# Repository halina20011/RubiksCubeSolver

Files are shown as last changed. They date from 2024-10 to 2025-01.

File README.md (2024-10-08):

# RubiksCubeSolver
silly Rubik's Cube solver that will stand next to my desk and obsessively solve and scramble the cube, helping me procrastinate more by staring at it...

### PCB
2 layer board made with KiCad

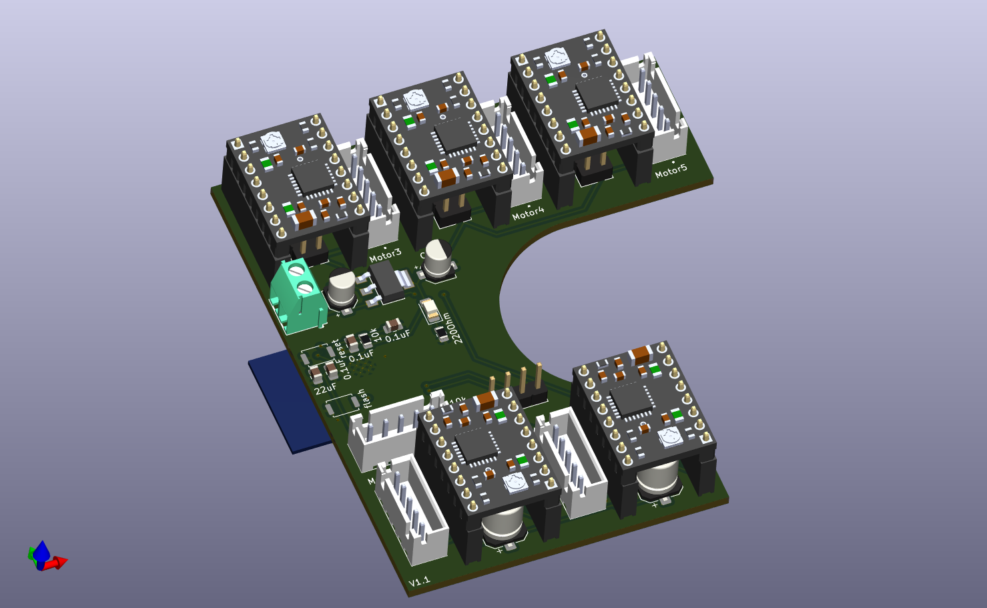
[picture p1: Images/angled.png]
angled


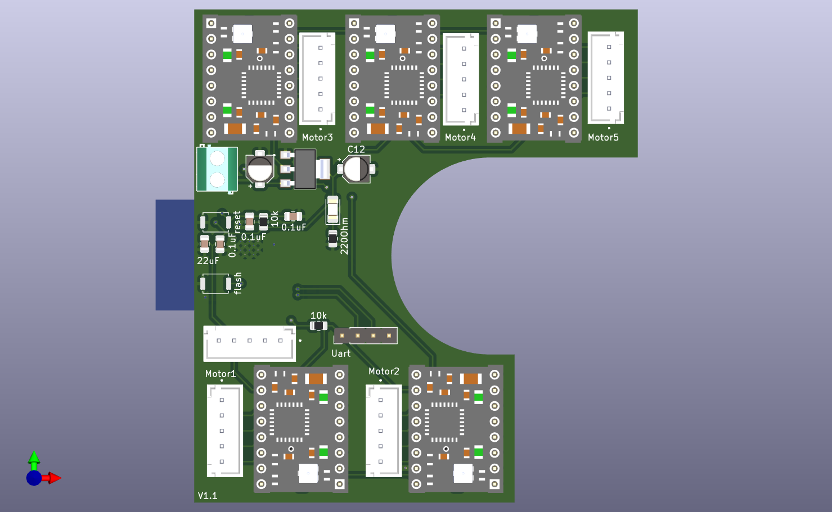
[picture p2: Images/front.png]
front


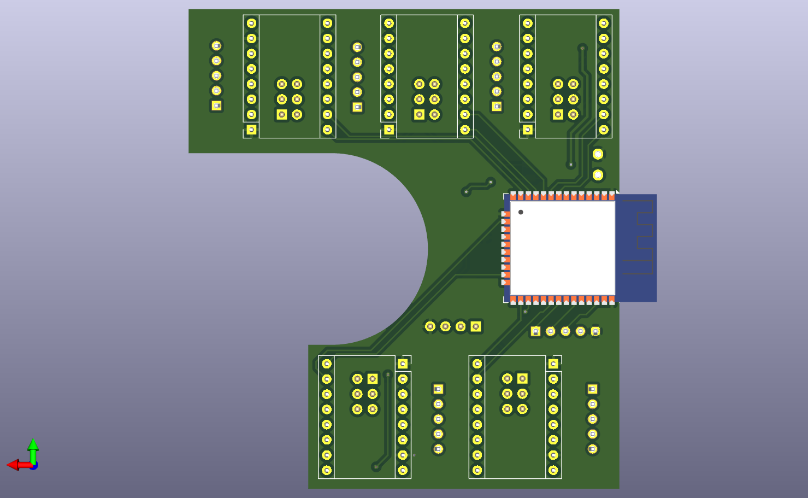
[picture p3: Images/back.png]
back


### cube solving algorithms
> TODO

### BOM
> TODO

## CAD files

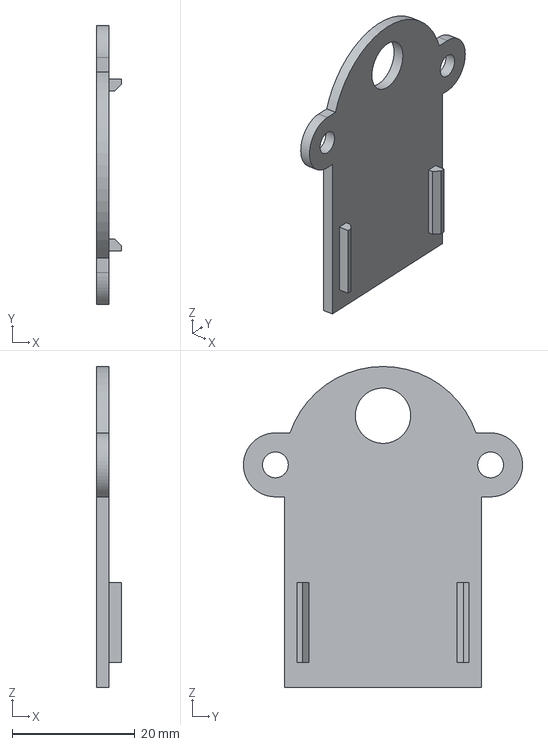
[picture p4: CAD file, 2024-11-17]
Model/Export/armEnclosurearm.step
4.00 x 45.4 x 52.2 mm

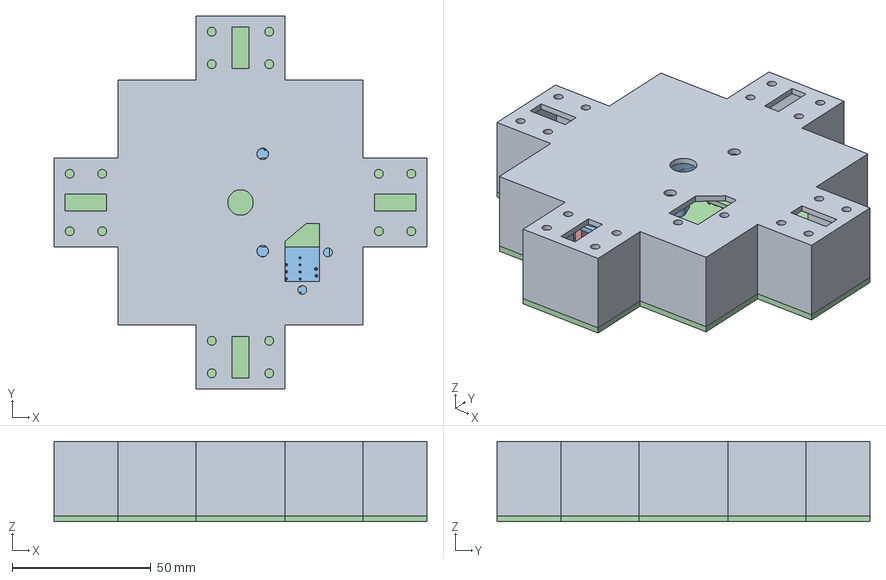
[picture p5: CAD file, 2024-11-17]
Model/rubiksCubeSolver.FCStd
134.4 x 134.4 x 29.0 mm
base
boardHolder
boardMotorHolder
B5B-XH-A(LF)(SN)
B5B-XH-A(LF)(SN)001
B5B-XH-A(LF)(SN)002
B5B-XH-A(LF)(SN)003
B5B-XH-A(LF)(SN)004
B5B-XH-A(LF)(SN)005
B5B-XH-A(LF)(SN)007
B5B-XH-A(LF)(SN)008
B5B-XH-A(LF)(SN)009
B5B-XH-A(LF)(SN)010
B5B-XH-A(LF)(SN)011
B5B-XH-A(LF)(SN)012
R_0805_2012Metric
B5B-XH-A(LF)(SN)014
B5B-XH-A(LF)(SN)015
B5B-XH-A(LF)(SN)016
B5B-XH-A(LF)(SN)017
B5B-XH-A(LF)(SN)018
B5B-XH-A(LF)(SN)019
C_0805_2012Metric
B5B-XH-A(LF)(SN)021
B5B-XH-A(LF)(SN)022
B5B-XH-A(LF)(SN)023
B5B-XH-A(LF)(SN)024
B5B-XH-A(LF)(SN)025
B5B-XH-A(LF)(SN)026
PinHeader_2x03_P254mm_Vertical
PinHeader_2x03_P254mm_Vertical001
CP_Elec_63x77
CP_Elec_63x078
TS1117BCW RPG
TS1117BCW RPG001
TS1117BCW RPG002
TS1117BCW RPG003
TS1117BCW RPG004
C_0805_2012Metric002
CP_Elec_63x079
CONN-TH_DB301V-3.5-2P-GN
CONN-TH_DB301V-3.5-2P-GN001
CONN-TH_DB301V-3.5-2P-GN002
CONN-TH_DB301V-3.5-2P-GN003
CONN-TH_DB301V-3.5-2P-GN004
CONN-TH_DB301V-3.5-2P-GN005
CONN-TH_DB301V-3.5-2P-GN006
CONN-TH_DB301V-3.5-2P-GN007
CONN-TH_DB301V-3.5-2P-GN008
CONN-TH_DB301V-3.5-2P-GN009
CONN-TH_DB301V-3.5-2P-GN010
CONN-TH_DB301V-3.5-2P-GN011
CONN-TH_DB301V-3.5-2P-GN012
CONN-TH_DB301V-3.5-2P-GN013
PinHeader_2x03_P254mm_Vertical002
LED_1206_3216Metric
CP_Elec_4x54
B5B-XH-A(LF)(SN)028
B5B-XH-A(LF)(SN)029
B5B-XH-A(LF)(SN)030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

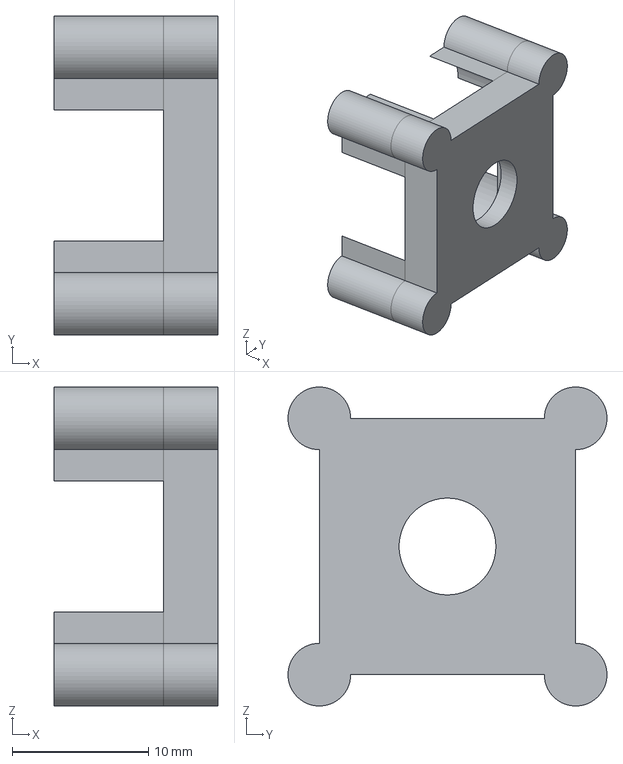
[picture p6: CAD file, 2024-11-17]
Model/Export/cubeConnector.step
12.0 x 23.4 x 23.4 mm

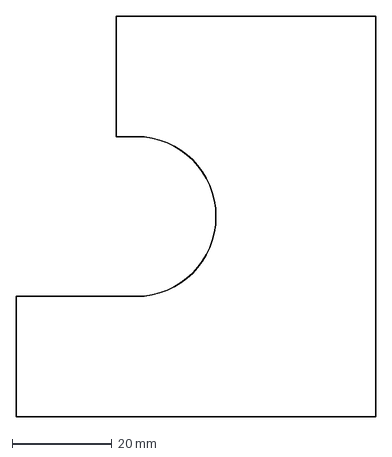
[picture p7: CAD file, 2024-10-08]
Model/pcbOutline.dxf
72.0 x 80.1 mm

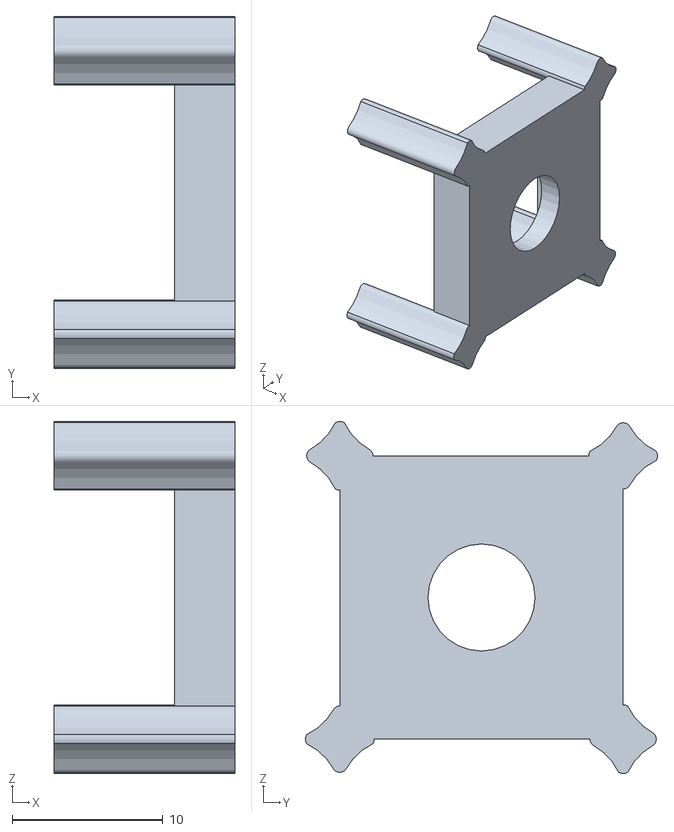
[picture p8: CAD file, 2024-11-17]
Model/Stl/rubiksCubeSolver-CubeConnector.stl
12.0 x 23.4 x 23.4

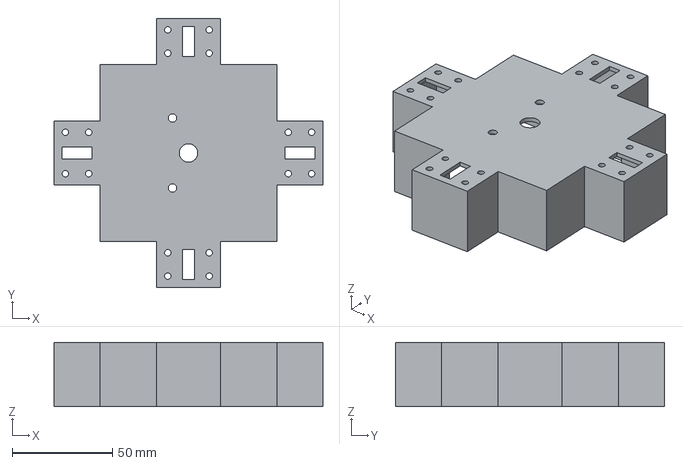
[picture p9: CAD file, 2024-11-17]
Model/Export/base.step
134.4 x 134.4 x 32.0 mm

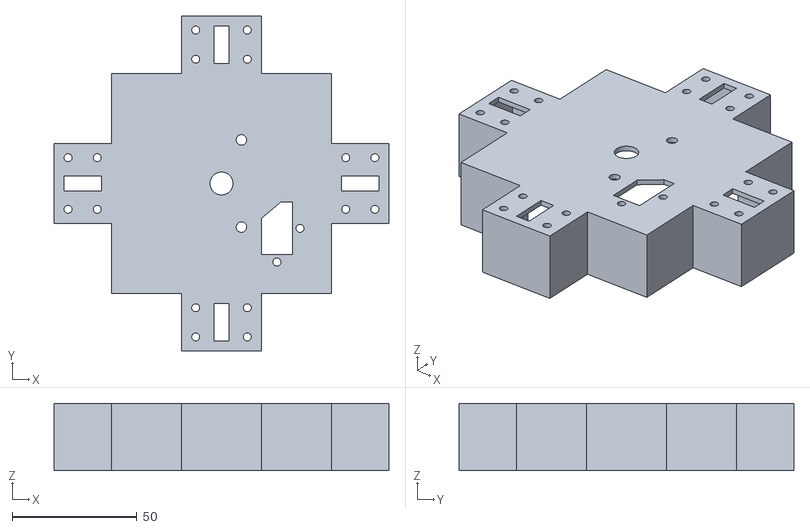
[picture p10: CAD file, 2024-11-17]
Model/Stl/rubiksCubeSolver-Basebase.stl
134.4 x 134.4 x 27.0

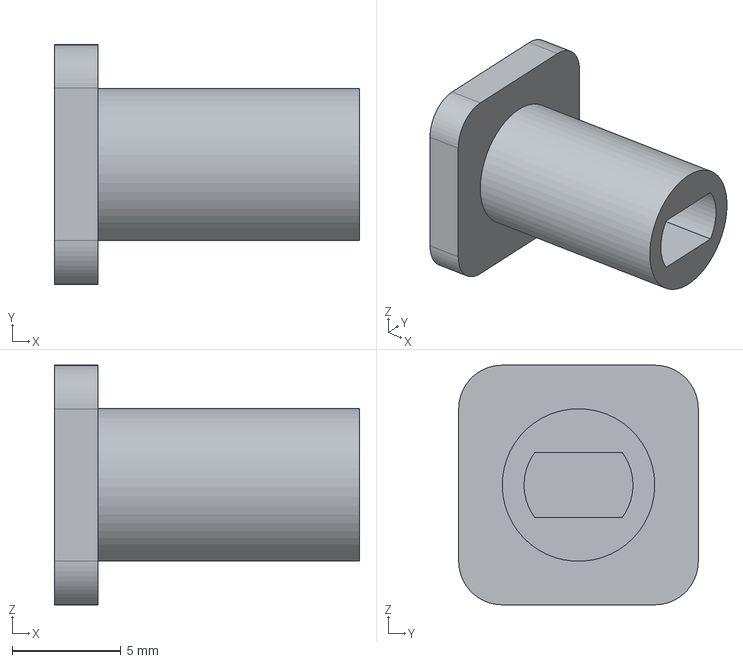
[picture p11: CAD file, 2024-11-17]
Model/Export/motorConnector.step
14.0 x 11.0 x 11.0 mm

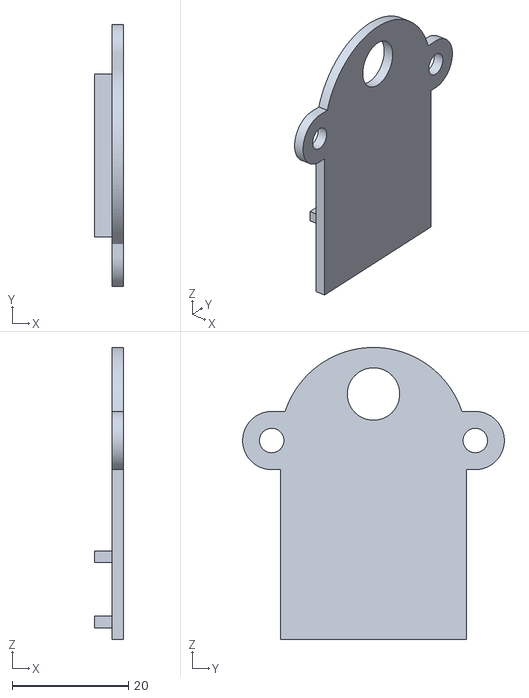
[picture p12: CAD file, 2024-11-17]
Model/Stl/rubiksCubeSolver-ArmPartArmEnclosure.stl
5.00 x 45.0 x 50.2

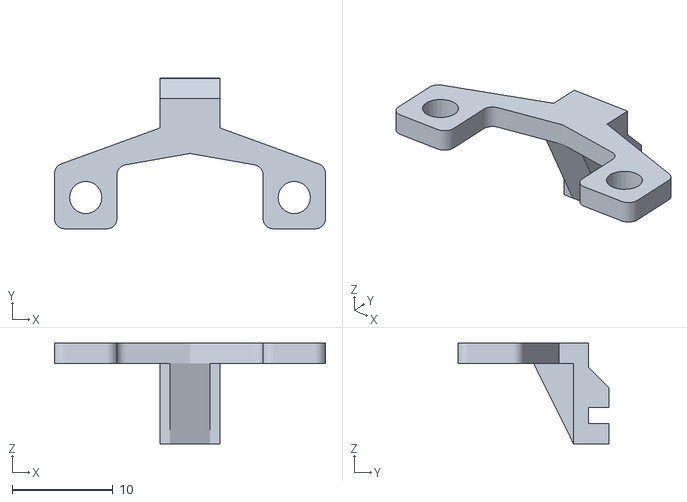
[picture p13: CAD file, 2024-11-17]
Model/Stl/rubiksCubeSolver-BaseboardHolder.stl
26.9 x 15.0 x 10.0

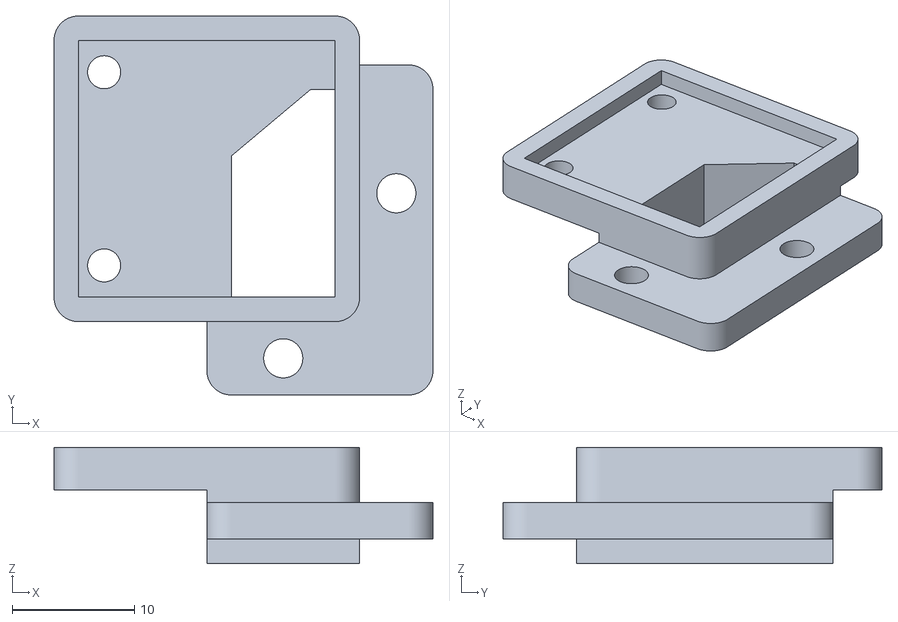
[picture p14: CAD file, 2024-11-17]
Model/Stl/sensorHolder.stl
31.0 x 31.0 x 9.50

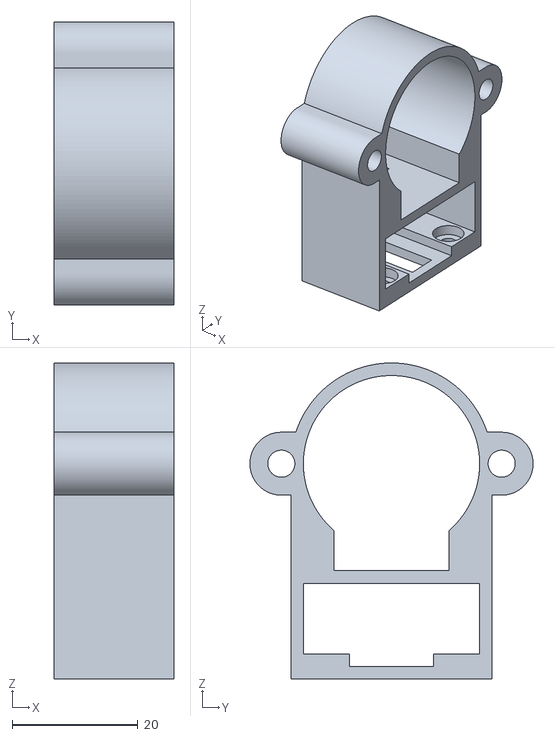
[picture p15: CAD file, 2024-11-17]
Model/Stl/rubiksCubeSolver-ArmPartArm.stl
19.0 x 45.0 x 50.2

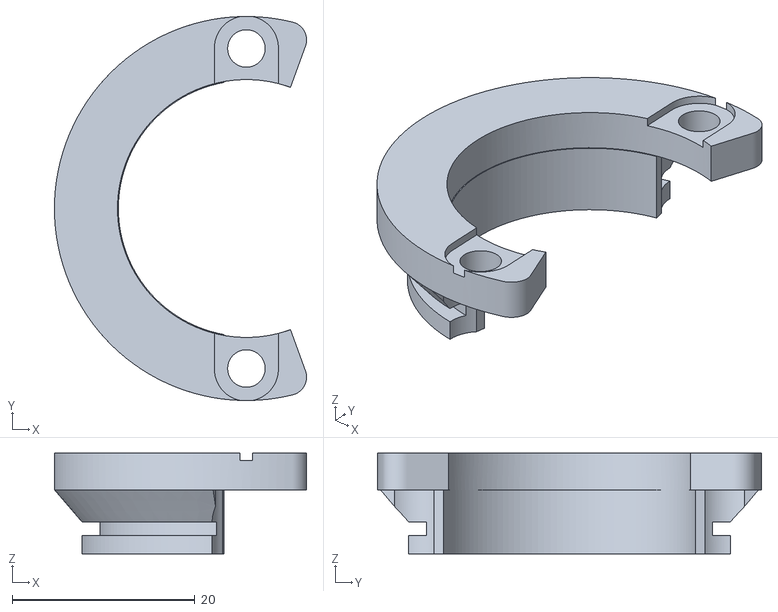
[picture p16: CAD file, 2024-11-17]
Model/Stl/rubiksCubeSolver-BaseboardMotorHolder.stl
27.6 x 42.0 x 11.0

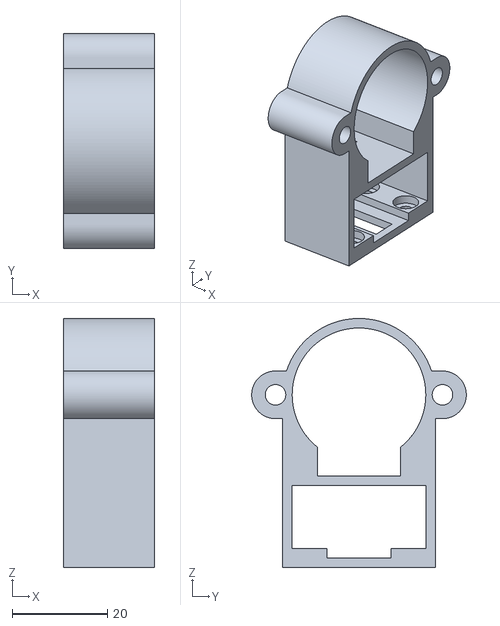
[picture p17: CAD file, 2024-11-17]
Model/Stl/arm.stl
19.0 x 45.0 x 52.2

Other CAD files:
Model/Stl/armEnclosure.3mf
Model/Stl/rubiksCubeSolver-MotorConnector.stl
Model/Stl/rubiksCubeSolver-ArmPartArmEnclosureHole.stl
Model/Stl/armEnclosure.stl
Model/Stl/base.stl
Model/Stl/cubeConnector.stl
Model/Stl/motorConnector.stl
Model/rubiksCube.blend

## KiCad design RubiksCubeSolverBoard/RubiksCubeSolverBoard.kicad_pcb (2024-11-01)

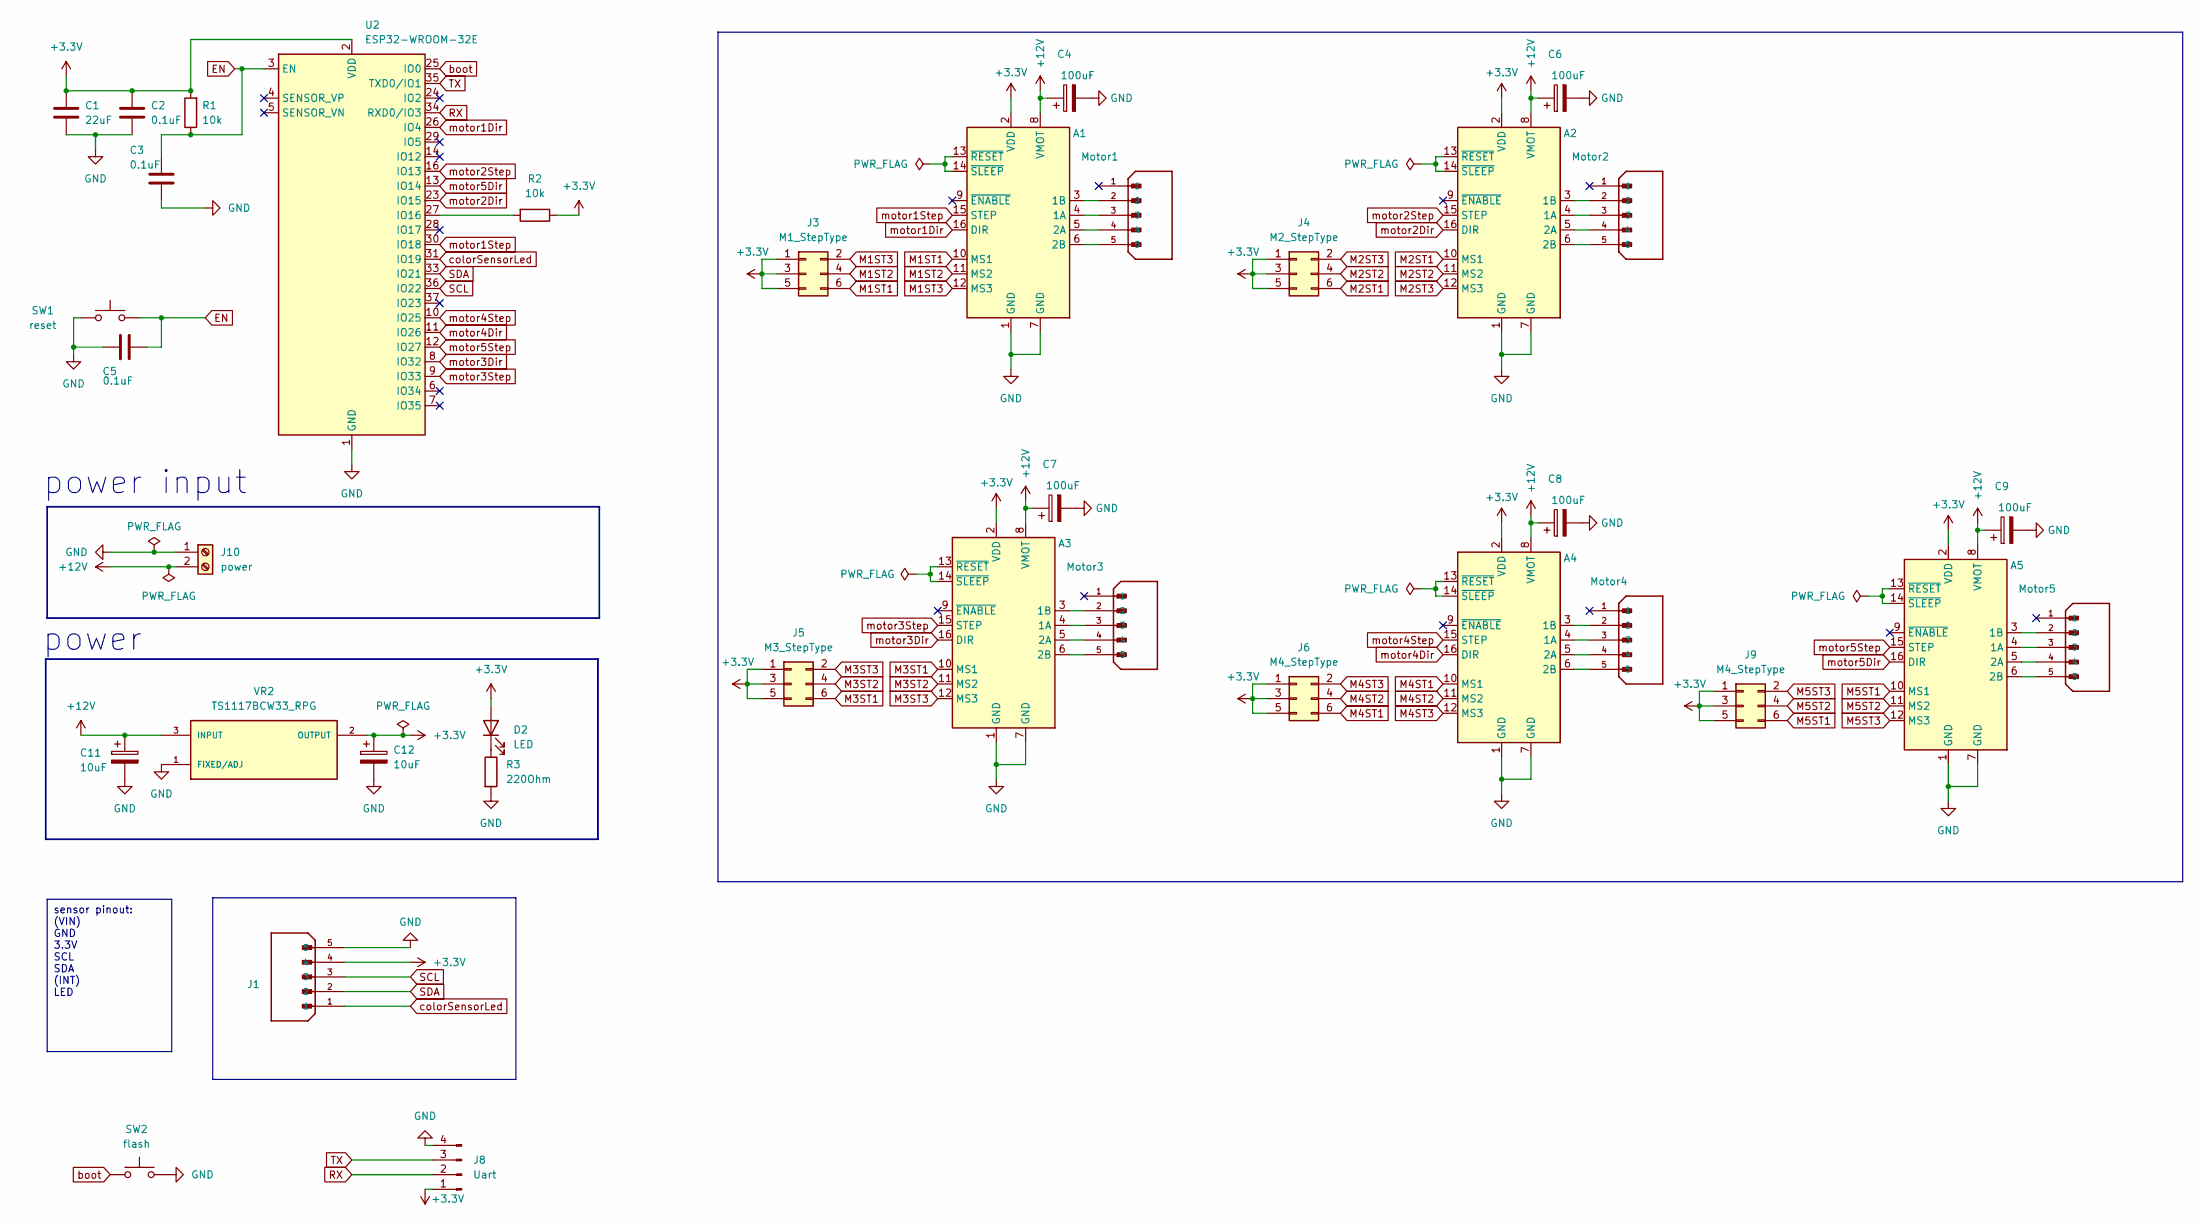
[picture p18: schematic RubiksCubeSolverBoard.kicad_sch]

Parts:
A1, A2, A3, A4, A5: Pololu_Breakout_A4988; A4988Mirrored
C1: 22uF; C_0805_2012Metric
C2, C3, C5: 0.1uF; C_0805_2012Metric
C4, C6, C7, C8, C9: 100uF; CP_Elec_6.3x7.7
C11, C12: 10uF; CP_Elec_4x5.4
D2: LED; LED_1206_3216Metric_Pad1.42x1.75mm_HandSolder
J1: colorSensor; JST_B5B-XH-A_LF__SN_; PARTREV N/A
J3: M1_StepType; PinHeader_2x03_P2.54mm_Vertical
J4: M2_StepType; PinHeader_2x03_P2.54mm_Vertical
J5: M3_StepType; PinHeader_2x03_P2.54mm_Vertical
J6, J9: M4_StepType; PinHeader_2x03_P2.54mm_Vertical
J7: Motor1; JST_B5B-XH-A_LF__SN_; PARTREV N/A
J8: Uart; PinHeader_1x04_P2.54mm_Vertical
J10: power; CONN-TH_DB301V-3.5-2P-GN
J14: Motor2; JST_B5B-XH-A_LF__SN_; PARTREV N/A
J18: Motor3; JST_B5B-XH-A_LF__SN_; PARTREV N/A
J22: Motor4; JST_B5B-XH-A_LF__SN_; PARTREV N/A
J26: Motor5; JST_B5B-XH-A_LF__SN_; PARTREV N/A
R1, R2: 10k; R_0805_2012Metric
R3: 220Ohm; R_0805_2012Metric
SW1: reset; SW_Push_SPST_NO_Alps_SKRK
SW2: flash; SW_Push_SPST_NO_Alps_SKRK
U2: ESP32-WROOM-32E; ESP32-WROOM-32D
VR2: TS1117BCW33_RPG; VREG_TS1117BCW33_RPG; PARTREV H1607

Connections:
+3.3V: A1.2 (VDD), A2.2 (VDD), A3.2 (VDD), A4.2 (VDD), A5.2 (VDD), C1.1, C2.1, C12.1, D2.2 (A), J1.4, J3.1, J3.3, J3.5, J4.1, J4.3, J4.5, J5.1, J5.3, J5.5, J6.1, J6.3, J6.5, J8.1, J9.1, J9.3, J9.5, R1.2, R2.1, U2.2 (VDD), VR2.2 (OUTPUT)
+12V: A1.8 (VMOT), A2.8 (VMOT), A3.8 (VMOT), A4.8 (VMOT), A5.8 (VMOT), C4.1, C6.1, C7.1, C8.1, C9.1, C11.1, J10.2, VR2.3 (INPUT)
EN: C3.1, C5.2, R1.1, SW1.2, U2.3 (EN)
GND: A1.1 (GND), A1.7 (GND), A2.1 (GND), A2.7 (GND), A3.1 (GND), A3.7 (GND), A4.1 (GND), A4.7 (GND), A5.1 (GND), A5.7 (GND), C1.2, C2.2, C3.2, C4.2, C5.1, C6.2, C7.2, C8.2, C9.2, C11.2, C12.2, J1.5, J8.4, J10.1, R3.2, SW1.1, SW2.2, U2.1 (GND), U2.15 (GND), U2.38 (GND), U2.39 (GND), VR2.1 (FIXED/ADJ)
M1ST1: A1.10 (MS1), J3.6
M1ST2: A1.11 (MS2), J3.4
M1ST3: A1.12 (MS3), J3.2
M2ST1: A2.10 (MS1), J4.6
M2ST2: A2.11 (MS2), J4.4
M2ST3: A2.12 (MS3), J4.2
M3ST1: A3.10 (MS1), J5.6
M3ST2: A3.11 (MS2), J5.4
M3ST3: A3.12 (MS3), J5.2
M4ST1: A4.10 (MS1), J6.6
M4ST2: A4.11 (MS2), J6.4
M4ST3: A4.12 (MS3), J6.2
M5ST1: A5.10 (MS1), J9.6
M5ST2: A5.11 (MS2), J9.4
M5ST3: A5.12 (MS3), J9.2
unnamed: A1.4 (1A), J7.3
unnamed: A1.3 (1B), J7.2
unnamed: A1.5 (2A), J7.4
unnamed: A1.6 (2B), J7.5
unnamed: A1.13 (~RESET), A1.14 (~SLEEP)
unnamed: A2.4 (1A), J14.3
unnamed: A2.3 (1B), J14.2
unnamed: A2.5 (2A), J14.4
unnamed: A2.6 (2B), J14.5
unnamed: A2.13 (~RESET), A2.14 (~SLEEP)
unnamed: A3.4 (1A), J18.3
unnamed: A3.3 (1B), J18.2
unnamed: A3.5 (2A), J18.4
unnamed: A3.6 (2B), J18.5
unnamed: A3.13 (~RESET), A3.14 (~SLEEP)
unnamed: A4.4 (1A), J22.3
unnamed: A4.3 (1B), J22.2
unnamed: A4.5 (2A), J22.4
unnamed: A4.6 (2B), J22.5
unnamed: A4.13 (~RESET), A4.14 (~SLEEP)
unnamed: A5.4 (1A), J26.3
unnamed: A5.3 (1B), J26.2
unnamed: A5.5 (2A), J26.4
unnamed: A5.6 (2B), J26.5
unnamed: A5.13 (~RESET), A5.14 (~SLEEP)
unnamed: D2.1 (K), R3.1
unnamed: R2.2, U2.27 (IO16)
RX: J8.2, U2.34 (RXD0/IO3)
SCL: J1.3, U2.36 (IO22)
SDA: J1.2, U2.33 (IO21)
TX: J8.3, U2.35 (TXD0/IO1)
boot: SW2.1, U2.25 (IO0)
colorSensorLed: J1.1, U2.31 (IO19)
motor1Dir: A1.16 (DIR), U2.26 (IO4)
motor1Step: A1.15 (STEP), U2.30 (IO18)
motor2Dir: A2.16 (DIR), U2.23 (IO15)
motor2Step: A2.15 (STEP), U2.16 (IO13)
motor3Dir: A3.16 (DIR), U2.8 (IO32)
motor3Step: A3.15 (STEP), U2.9 (IO33)
motor4Dir: A4.16 (DIR), U2.11 (IO26)
motor4Step: A4.15 (STEP), U2.10 (IO25)
motor5Dir: A5.16 (DIR), U2.13 (IO14)
motor5Step: A5.15 (STEP), U2.12 (IO27)

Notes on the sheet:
sensor pinout: (VIN) GND 3.3V SCL SDA (INT) LED
power input
power

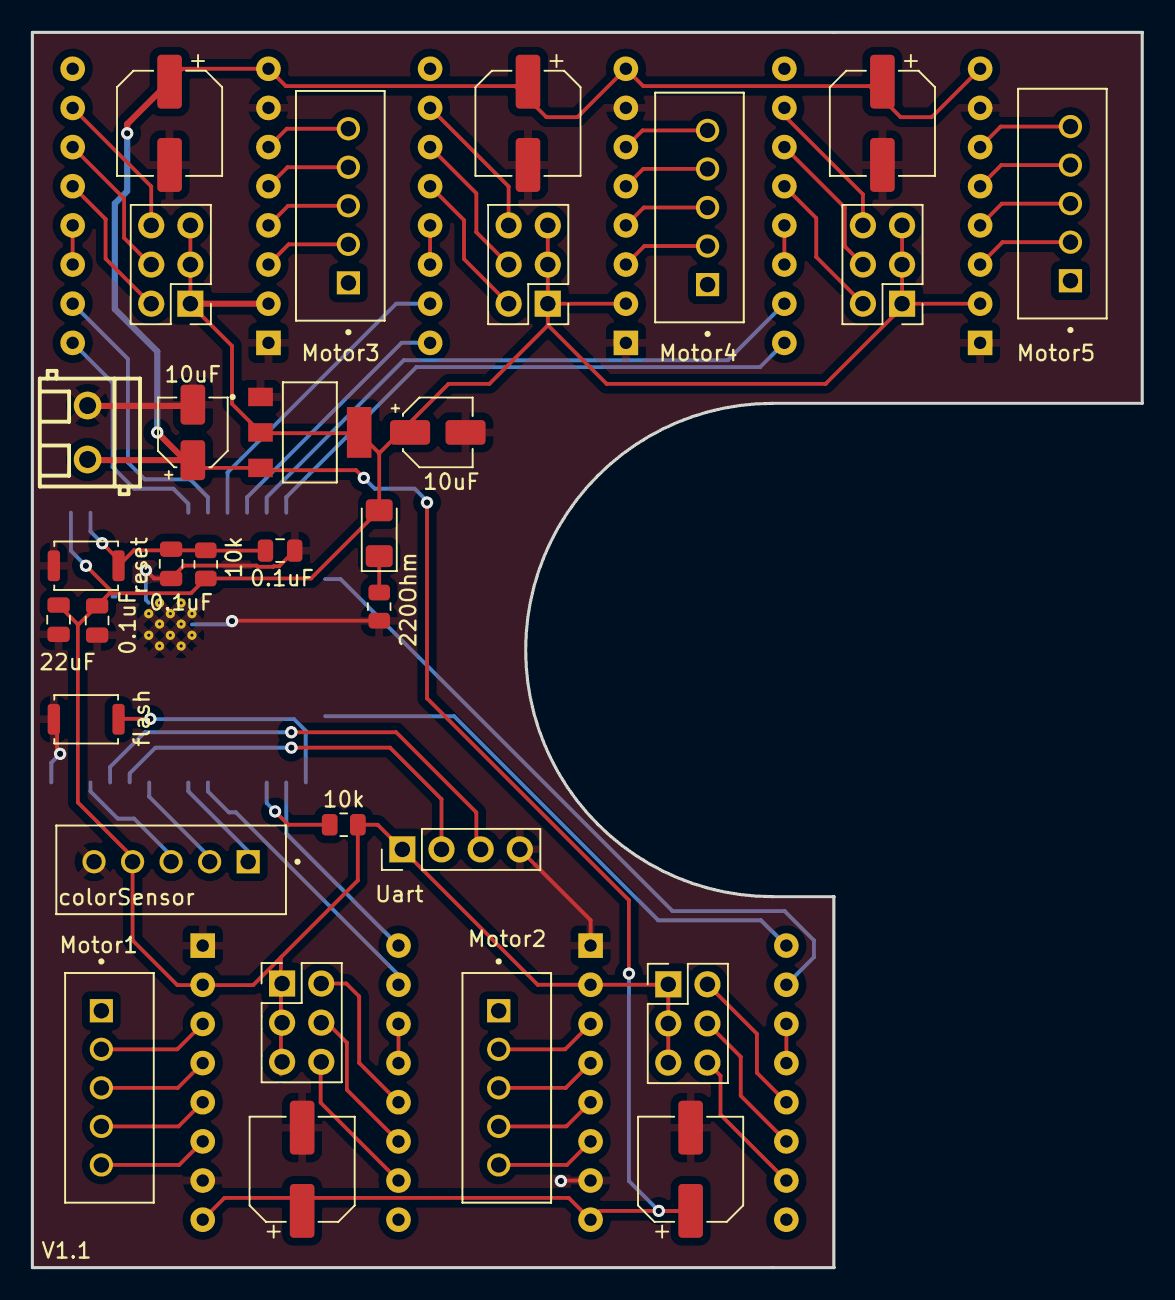
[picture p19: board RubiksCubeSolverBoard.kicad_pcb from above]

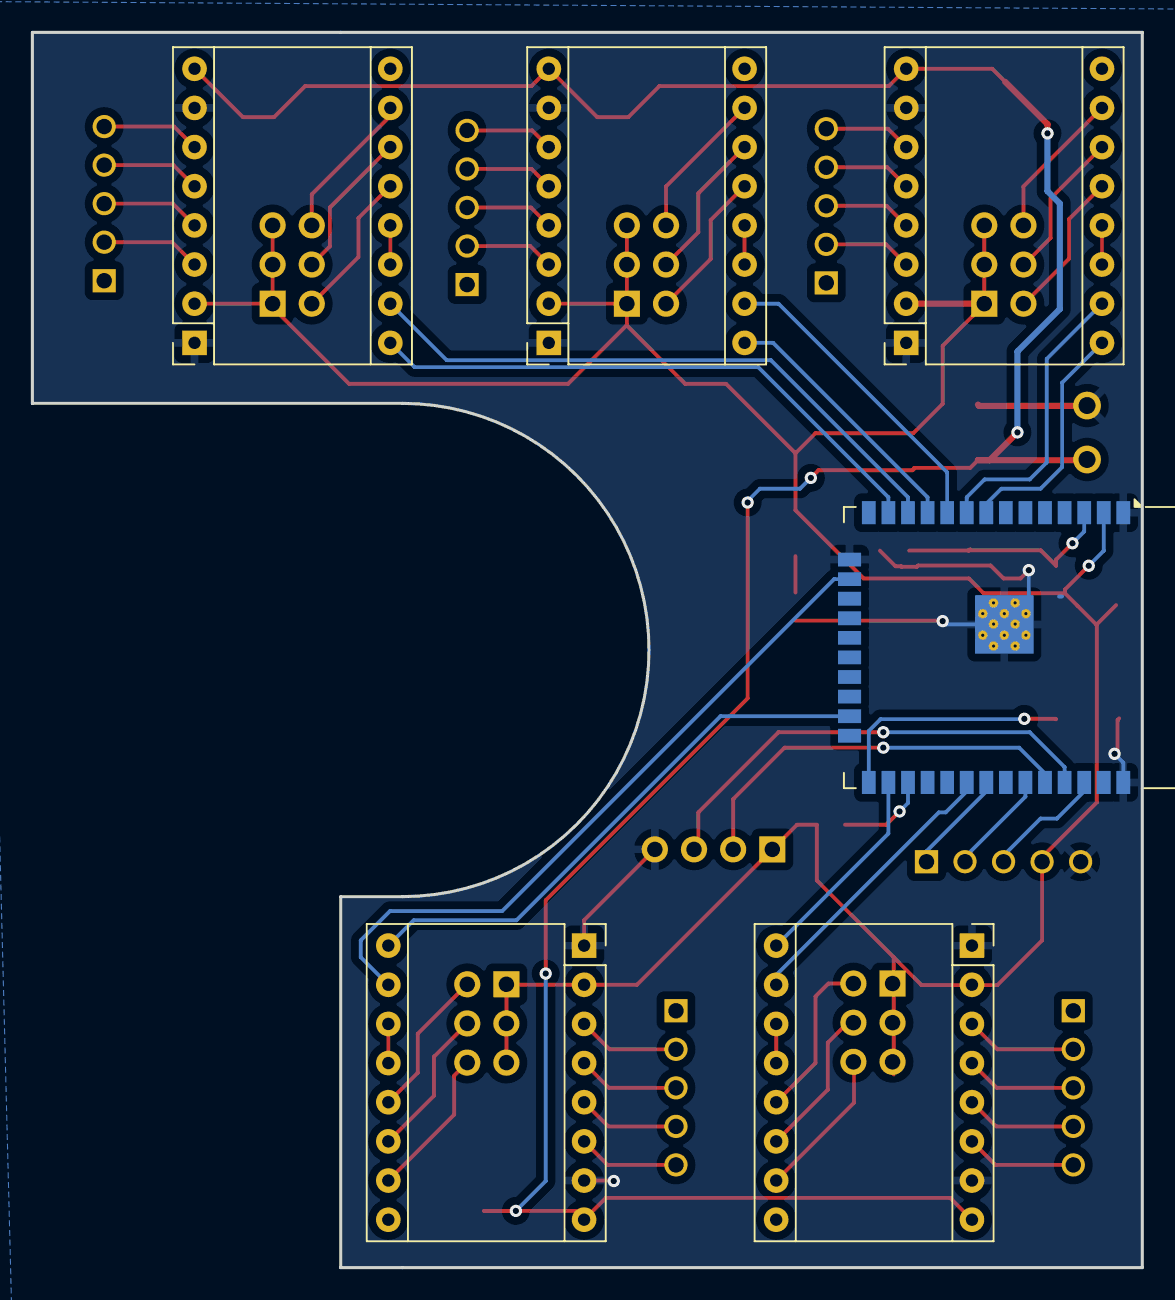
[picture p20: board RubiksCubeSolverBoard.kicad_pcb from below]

Board: 2 copper layers, 72.0 x 80.1 mm, 37 parts (6 on the bottom side), 62 nets.

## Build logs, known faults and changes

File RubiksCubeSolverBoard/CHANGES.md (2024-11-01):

### Version 1
- BUG: wrong motor connector connections

### Version 1.1
- FIX: wrong motor connector connection
- changed power connector to screw terminal
- show component values on silk screen
- replaced radial capacitors with smd ones
- stepper motor step mode connector changed to 02x03 header
- added pcb version number

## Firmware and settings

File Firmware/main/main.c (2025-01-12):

#include "motor.h"
#include "pinout.h"

#include "nvs_flash.h"

#include "sensor.h"
#include "wifi.h"
#include "mcode.h"

void mainLoop(){
    while(1){
        processCommandQueue();
    }
}

void app_main(void){
    ESP_ERROR_CHECK(nvs_flash_init());

    commandQueueInit();
    // sensorInit(1);
    motorsInit();
    wifiInit();
    xTaskCreate(mainLoop, "MainLoop", 4096, NULL, 2, NULL);
    
    // bool led = 0;
    // struct Color color = {};
    // while(1){
    //     // motorTest(&m1);
    //     // motorTest(&m4);
    //     // sensorLed(led);
    //     getColor(&color);
    //     printf("%i %i %i\n", color.r, color.g, color.b);
    //     // led = !led;
    //     vTaskDelay(pdMS_TO_TICKS(100));
    // }
}

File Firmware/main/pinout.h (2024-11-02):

#ifndef __PINOUT__
#define __PINOUT__

// #include "freertos/FreeRTOS.h"
// #include "driver/gpio.h"

#define MOTOR1_DIR  GPIO_NUM_4
#define MOTOR1_STEP GPIO_NUM_18

#define MOTOR2_DIR  GPIO_NUM_15
#define MOTOR2_STEP GPIO_NUM_13

#define MOTOR3_DIR  GPIO_NUM_32
#define MOTOR3_STEP GPIO_NUM_33

#define MOTOR4_DIR  GPIO_NUM_26
#define MOTOR4_STEP GPIO_NUM_25

#define MOTOR5_DIR  GPIO_NUM_14
#define MOTOR5_STEP GPIO_NUM_27

#endif

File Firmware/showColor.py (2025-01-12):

import tkinter as tk
import serial

# Configuration
SERIAL_PORT = "/dev/ttyUSB0"  # Path to the serial device
BAUD_RATE = 115200  # Match the baud rate of your device
WINDOW_WIDTH = 800
WINDOW_HEIGHT = 600

def read_rgb_values(serial_connection):
    """Reads a line from the serial port and parses it into RGB values."""
    try:
        line = serial_connection.readline().decode("utf-8").strip()
        r, g, b = map(int, line.split())
        return (r, g, b)
    except (ValueError, UnicodeDecodeError):
        print(f"Invalid line received: {line}")
        return None

def update_color(canvas, serial_connection):
    """Reads RGB values and updates the canvas color."""
    color = read_rgb_values(serial_connection)
    if color:
        # Convert RGB to hex color
        hex_color = f"#{color[0]:02x}{color[1]:02x}{color[2]:02x}"
        canvas.config(bg=hex_color)
    # Continue waiting for the next line
    canvas.after(1, update_color, canvas, serial_connection)

def main():
    # Open the serial connection
    try:
        serial_connection = serial.Serial(SERIAL_PORT, BAUD_RATE, timeout=None)  # Blocking mode
    except serial.SerialException as e:
        print(f"Error opening serial port: {e}")
        return

    # Set up the tkinter window
    root = tk.Tk()
    root.title("Color Display")
    root.geometry(f"{WINDOW_WIDTH}x{WINDOW_HEIGHT}")
    canvas = tk.Canvas(root, width=WINDOW_WIDTH, height=WINDOW_HEIGHT)
    canvas.pack(fill="both", expand=True)

    # Start the update loop
    update_color(canvas, serial_connection)
    root.mainloop()

    # Close the serial connection when done
    serial_connection.close()

if __name__ == "__main__":
    main()

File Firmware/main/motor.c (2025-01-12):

#include "motor.h"

struct Motor motors[5] = {};

void motorsInit(){
    motorInit(&motors[0], MOTOR1_DIR, MOTOR1_STEP);
    motorInit(&motors[1], MOTOR2_DIR, MOTOR2_STEP);
    motorInit(&motors[2], MOTOR3_DIR, MOTOR3_STEP);
    motorInit(&motors[3], MOTOR4_DIR, MOTOR4_STEP);
    motorInit(&motors[4], MOTOR5_DIR, MOTOR5_STEP);
}

void motorInit(struct Motor *motor, uint8_t dirPin, uint8_t stepPin){
    motor->dirPin = dirPin;
    motor->stepPin = stepPin;

    gpio_config_t pinConf = {};
    // dissable interrupt
    pinConf.intr_type = GPIO_INTR_DISABLE;
    // set them as output mode
    pinConf.mode = GPIO_MODE_OUTPUT;
    // bit masl for targeted pins
    pinConf.pin_bit_mask = (1ULL << dirPin) | (1ULL << stepPin);
    // dissable pull up, pull down
    pinConf.pull_down_en = 0;
    pinConf.pull_up_en = 0;
    gpio_config(&pinConf);
}

#define DELAY_MS    100
#define STEPS       5000

void motorTest(struct Motor *motor){
    gpio_set_level(motor->dirPin, 1);

    for(uint32_t i = 0; i < STEPS; i++){
        gpio_set_level(motor->stepPin, 1);
        esp_rom_delay_us(DELAY_MS);
        gpio_set_level(motor->stepPin, 0);
        esp_rom_delay_us(DELAY_MS);
    }

    vTaskDelay(100);
}

void motorRotateDeg(int id, int deg, int direction){
    bool dir = (direction != 0);
    const struct Motor *motor = &motors[id];
    gpio_set_level(motor->dirPin, dir);

    for(uint32_t i = 0; i < deg; i++){
        gpio_set_level(motor->stepPin, 1);
        esp_rom_delay_us(DELAY_MS);
        gpio_set_level(motor->stepPin, 0);
        esp_rom_delay_us(DELAY_MS);
    }
}

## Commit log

2024-04-13 webgl2 + cube
    [rubiksCube.blend]
2024-09-25 1 layer board
    [RubiksCubeSolverBoard.kicad_pcb, RubiksCubeSolverBoard.kicad_sch]
2024-10-08 2 layer pcb
    [RubiksCubeSolverBoard.kicad_pcb, RubiksCubeSolverBoard.kicad_sch, pcbOutline.dxf]
2024-11-01 pcb v1.1
    [RubiksCubeSolverBoard.kicad_pcb, RubiksCubeSolverBoard.kicad_sch]
2024-11-02 controlling stepper motors (delay func)
2024-11-17 modeling + exported file + stl files
    [arm.stl, armEnclosure.3mf, armEnclosure.stl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]
2025-01-12 color sensor + socket primitive command parser
2025-01-14 switched to websockets
